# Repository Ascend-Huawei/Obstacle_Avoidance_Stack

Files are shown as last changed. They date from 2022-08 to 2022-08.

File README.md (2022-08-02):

# HiFly obstacle avoidance stack
This is a custom hardware sensor module to bring obstacle avoidance capabilities to small robotics. It is a fully independent module based on Arduino Nano IoT 33.

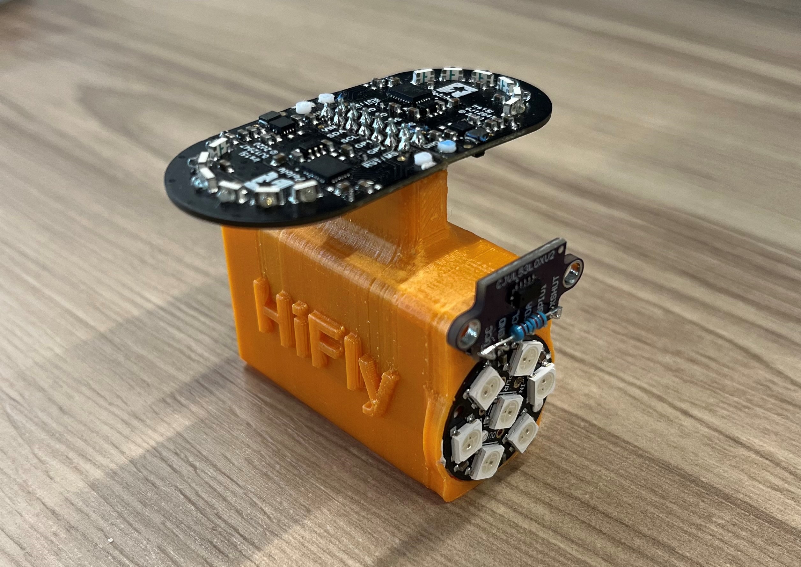
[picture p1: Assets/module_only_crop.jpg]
image info


## Features
General
 - Wifi 
 - Bluetooth
 - Independent Lipo battery based power system
 - 7 RBG LED ring for display or user interaction
 - Total weight only 35g

 Sensing
 - 360 degree lateral ToF sensing using 6 wide FoV channels
 - 1 narrow ToF sensor facing forward
 - 6 axis IMU

## Required knowledge to do the assembly
- 3D printing 
- Arduino/MCU programming
- Electronics - soldering, dupont connectors, etc

## Links
- [Assembly guide](ASSEMBLY.md)
- HiFly repo

# Parts list

### MCU
- [Arduino Nano iot 33](https://www.amazon.ca/Arduino-Nano-33-IoT/dp/B07VW9TSKD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)

### Sensors
- 2 x [OPT3101](https://www.robotshop.com/ca/en/3-channel-wide-fov-time-of-flight-distance-sensor-opt3101-no-headers.html)
- [ToF VL53L0X](https://www.amazon.ca/gp/product/B097SJ37DX/ref=ppx_yo_dt_b_search_asin_title?ie=UTF8&psc=1)

### Display
- [Adafruit NeoPixel Jewel](https://www.amazon.ca/gp/product/B00Q9R8QUO/ref=ppx_yo_dt_b_search_asin_title?ie=UTF8&psc=1) 

### Power
- [Battery, connector](https://www.amazon.ca/gp/product/B08NYDQ3HZ/ref=ppx_yo_dt_b_search_asin_title?ie=UTF8&psc=1)
- [Power converter](https://leeselectronic.com/en/product/15123-pololu-5v-step-up-voltage-regulator-u1v11f5.html)

### Circuit components (available in many kits)
- 30 AWG wires
- 2 NPN 8050 transistors
- 3 10k ohm resistors
- Dupoint wiring kit (be able to make 2x7, 1x6 connections)
- switch (available in many kits)

### Assembly
- 3D printing tools
- soldering tools
- tweezers, clippers, etc very useful

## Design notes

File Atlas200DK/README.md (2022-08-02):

# HiFly Obstacle Avoidance System
This is a setup guide to connect Tello Drone, Atlas200DK devkit board, Obstacle Avoidance Stack components together through WiFi communication.

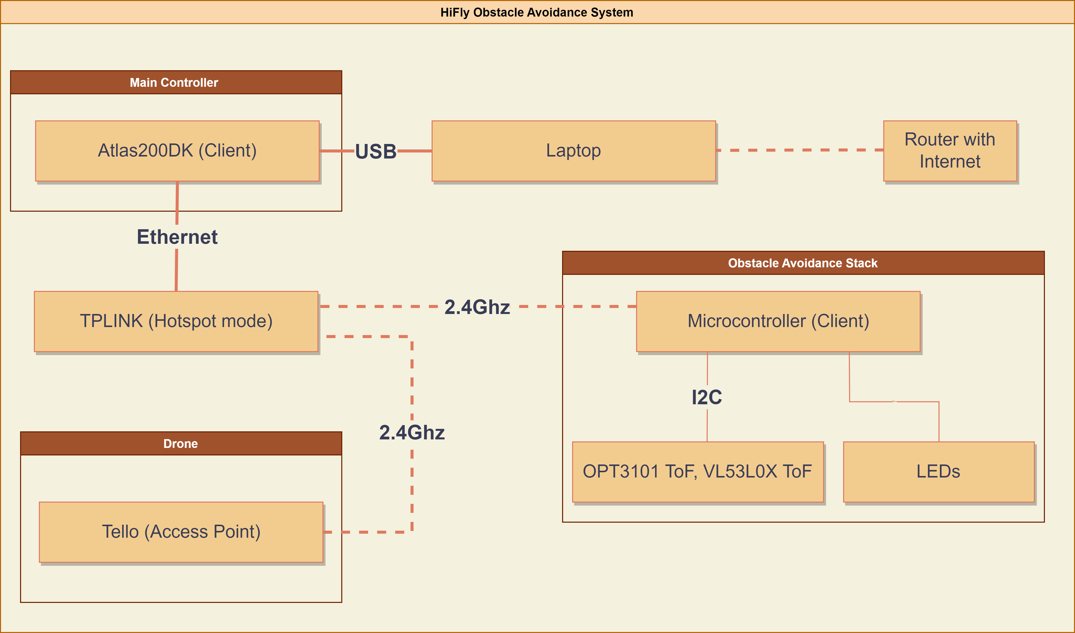
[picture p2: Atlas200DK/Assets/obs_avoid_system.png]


## Prerequisites
- Atlas200DK HiFly project setup finished 
- Obstacle Avoidance Stack setup finished

## Setup files and networking
The Arduino in the Obs Avoidance stack sends data to a specific IP and port defined in its code. This has to be the IP of the Atlas200DK and the port defined in the tello.py. The 200DK and Arduino are on the same subnet as the TPLINK router, so communication between them is straightforward.

The Tello is on a different network, so port forwarding must be defined to allow the Atlas200DK to receive data from the Tello.

### Steps
- Move 4 files to the Atlas200DK - 01-netcfg.yaml, ObsAvoid.py, simple_takeoff.py, tello.py
- Setup TPLINK router: Connect 2.4Ghz to Tello, setup port forwarding
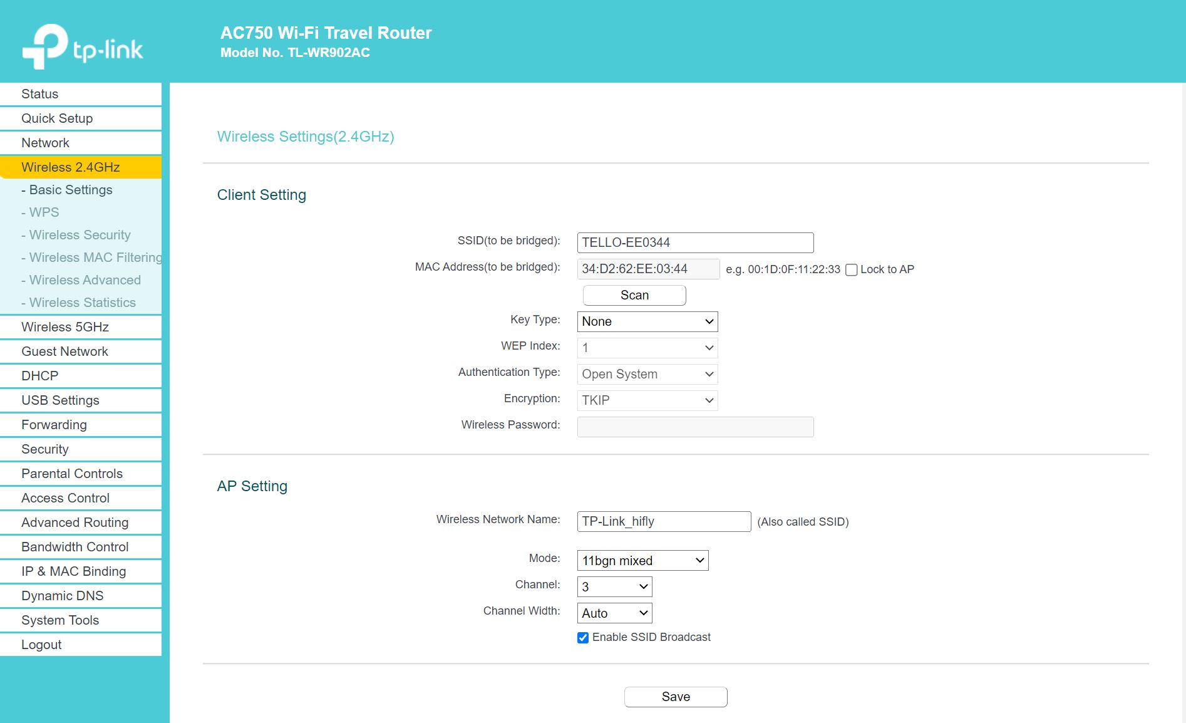
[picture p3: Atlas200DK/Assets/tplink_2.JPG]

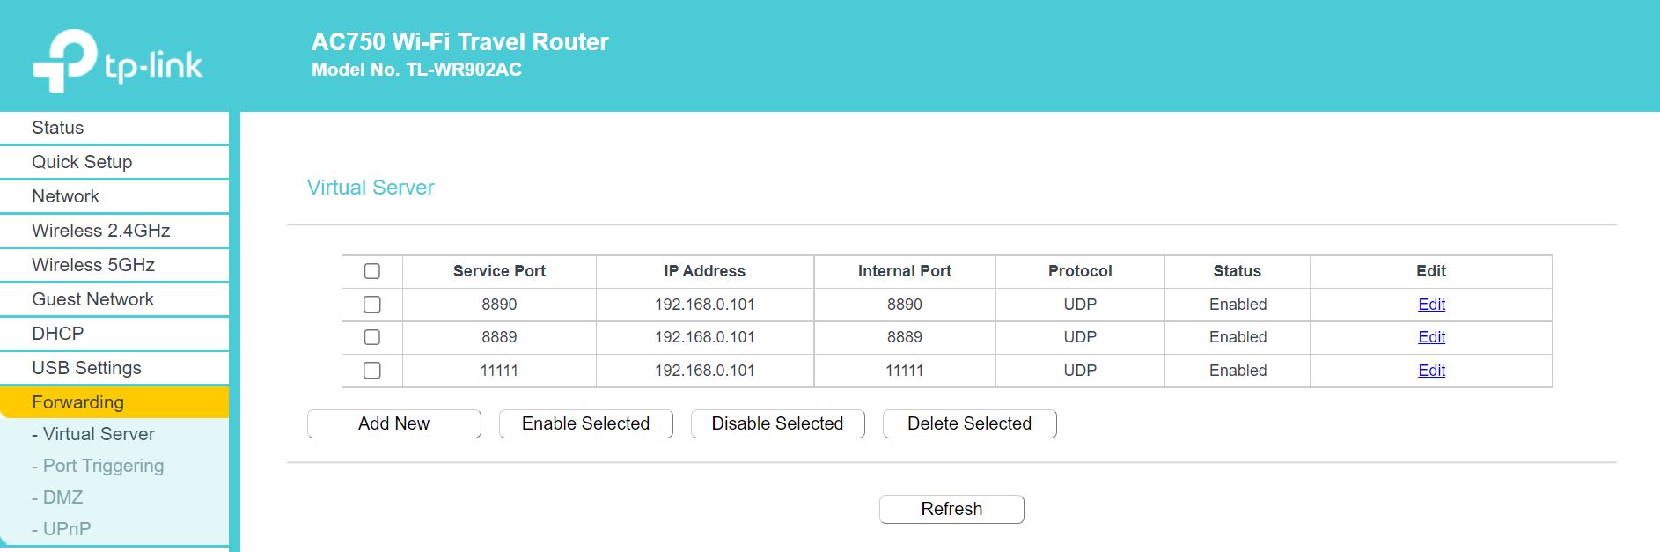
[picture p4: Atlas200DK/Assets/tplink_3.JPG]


- Change the netcfg.yaml under /etc/netplan/*.yaml to the new 01-netcfg.yaml

- From the Atlas200DK, try the following ping tests. If all works, networking setup is successful!: 
    - ping 192.168.0.1      # Router
    - ping 192.168.0.102    # Arduino
    - ping 192.168.1.0      # Tello

- Change the pip installed tello.py to the new tello.py. The installed one can be found by the python code: from djitellopy import Tello, print(tello.__file__)

## Running example
The intended core functionality of this project is access to Obstacle Avoidance sensor readings from the Atlas200DK through the modified tello.py class. A simple algorithm to process these sensor readings and return velocities which can be used to avoid the sensed obstacles is also provided, but only for basic demonstration purposes.

The simple_takeoff.py script uses the calculate_drone_velocity from ObsAvoid.py to implement the above mentioned basic algorithm. Set the LIVE_FLAG inside the script to either only print the sensor readings and computed velocities, or actually send them to the Tello drone.
- python3 simple_takeoff.py

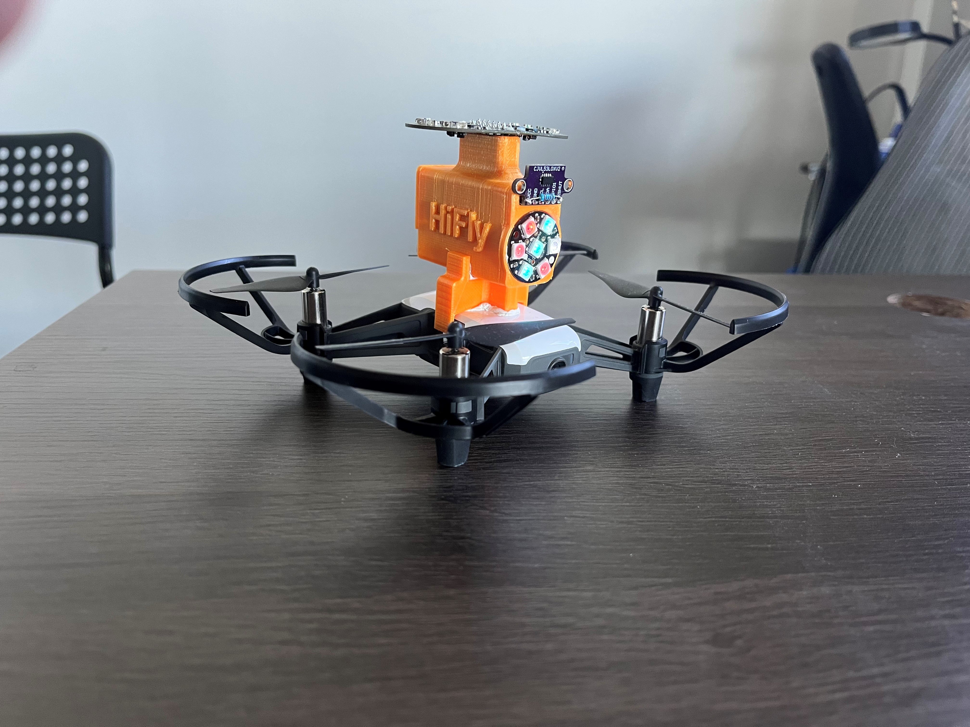
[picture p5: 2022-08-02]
Assets/module_drone.jpg

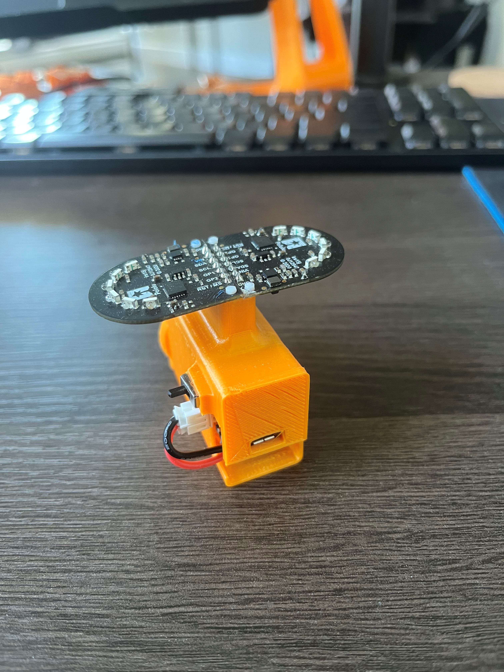
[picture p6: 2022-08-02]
Assets/hatch4.jpg

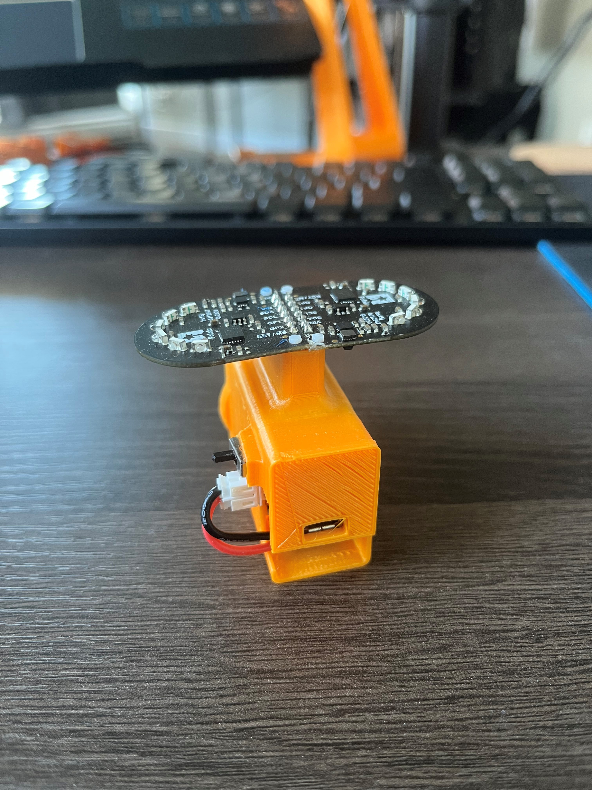
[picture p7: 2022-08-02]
Assets/hatch2.jpg

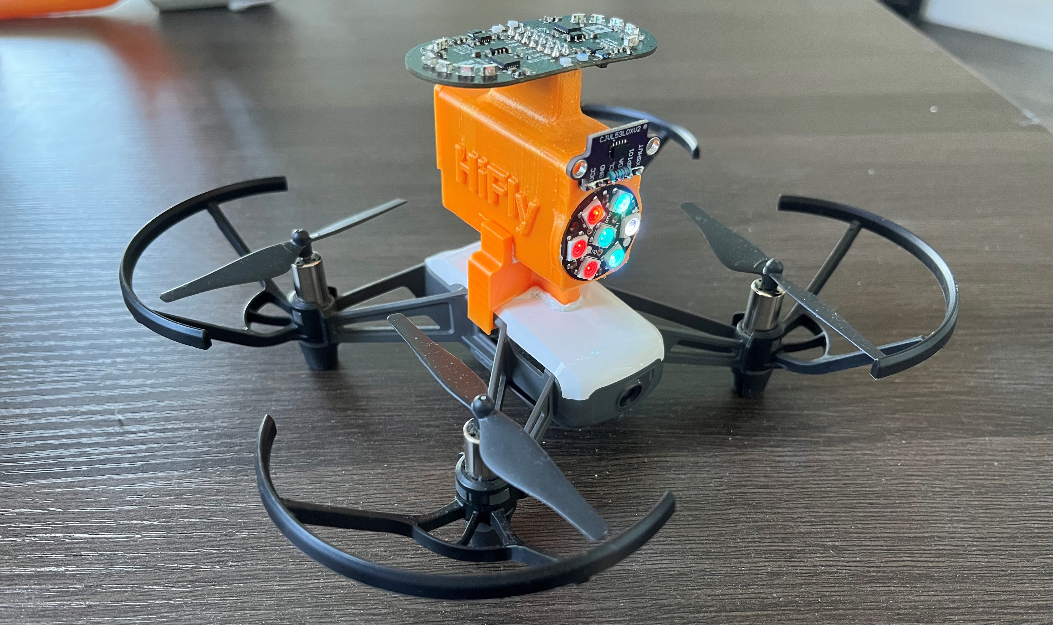
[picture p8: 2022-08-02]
Assets/module_drone2_crop.jpg

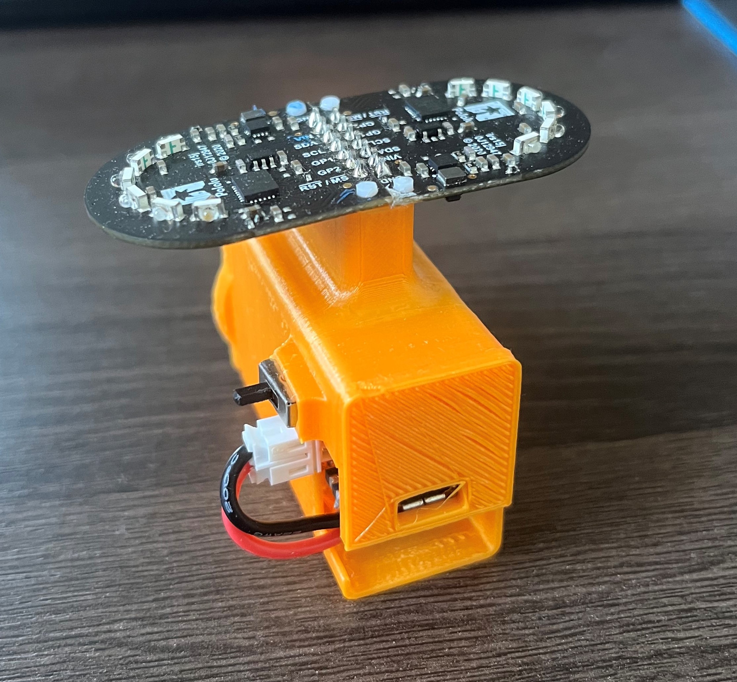
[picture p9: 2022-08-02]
Assets/hatch.jpg

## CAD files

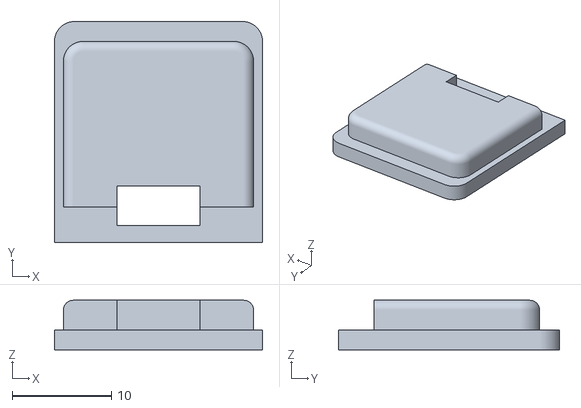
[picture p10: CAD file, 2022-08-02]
CAD/back_cover.stl
21.0 x 22.3 x 5.00

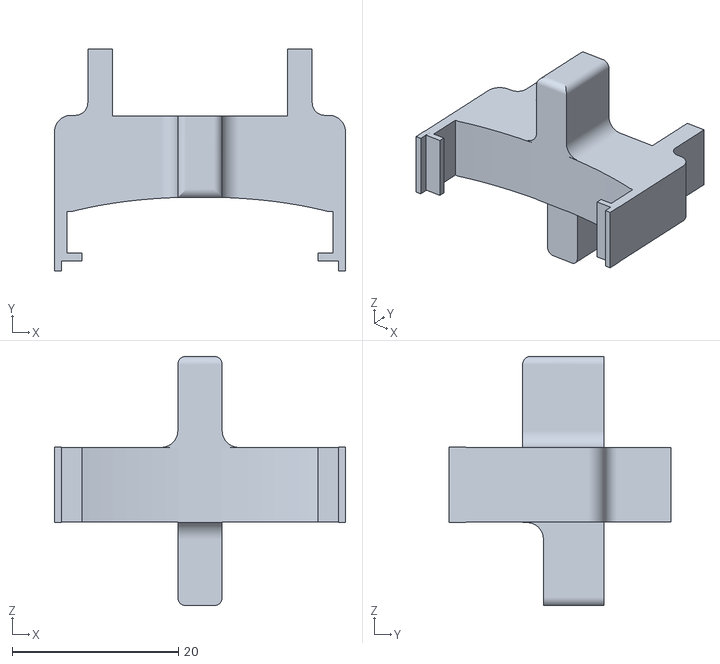
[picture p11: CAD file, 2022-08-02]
CAD/tello_clip.stl
35.0 x 26.8 x 30.0

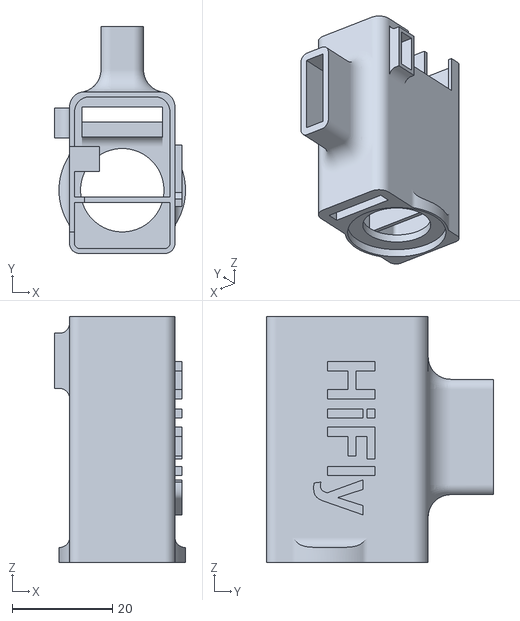
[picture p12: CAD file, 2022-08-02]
CAD/shell.stl
26.1 x 45.2 x 49.0

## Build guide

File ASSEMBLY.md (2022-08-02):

# Arduino packages to download
- WiFiNINA
- Adafruit NeoPixel
- DFRobot_VL53L0X
- OPT3101
# 3D printing the frame
- The frame is one large part, can be printed facing downwards (LED side on bed) and only using supports for the 'chimney' and LED ring.

- There is another small part to pop into the back, used to enclose the frame.

- When using with the DJI Tello drone, there is also a clip-mount component available.

# OPT3101 same I2C address workaround
The OPT3101 sensors share a hardcoded I2C address, which is an issue when we want to use two or more of them at the same time. The workaround used here is to use transistors to control which sensor the SDA line is connected to. The transistors can be toggled through the firmware to select which sensor to read from.

# Preparing the electronics
- Solder the two resistors and NPN transistors together according to the schematic. You can also add a heatshrink wrap the whole resistor branch.

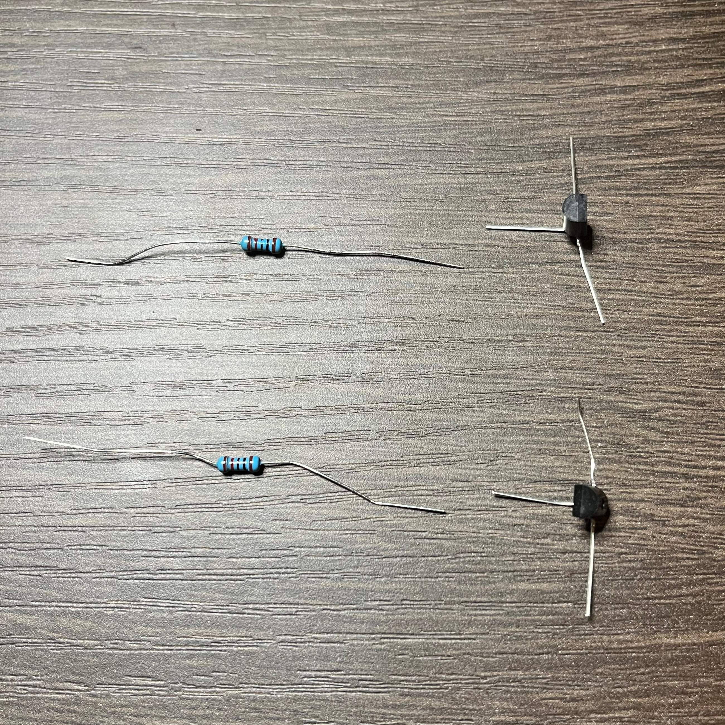
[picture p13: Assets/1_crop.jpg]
- - 
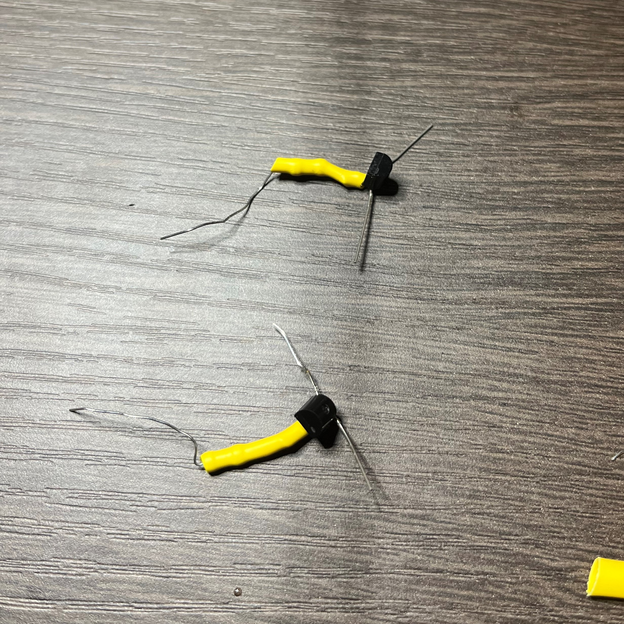
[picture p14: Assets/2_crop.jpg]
- - 

- Solder this combined component to the arduino according to the schematic. Try to have the component as flat as possible to conserver space.

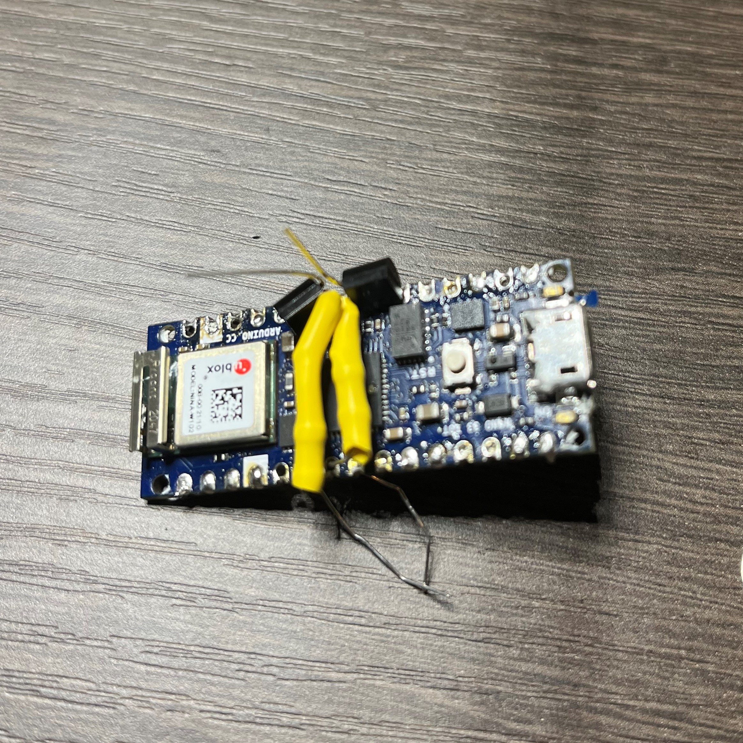
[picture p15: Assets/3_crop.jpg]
- - 

- Solder the 4 Vdd wires and 5 GND wires to the arduino, apply shrinkwrap.
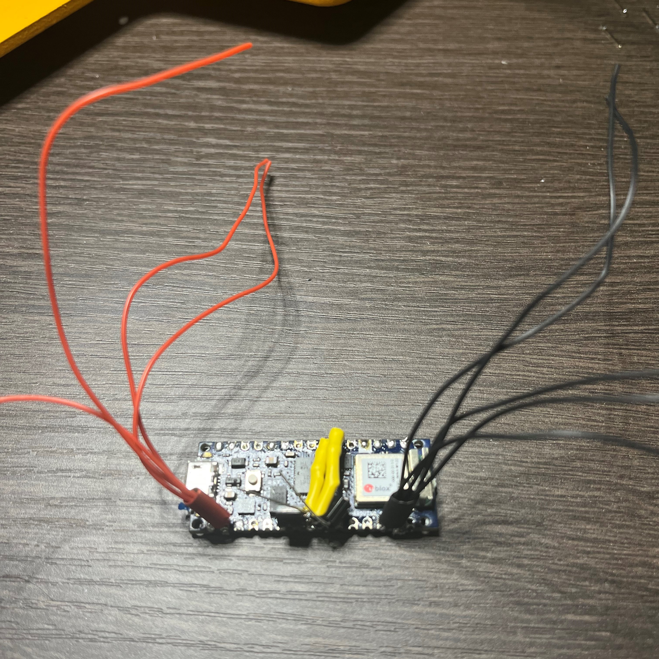
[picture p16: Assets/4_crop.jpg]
- - 

- Solder the Vin and 3 I2C scl wires to the arduino.
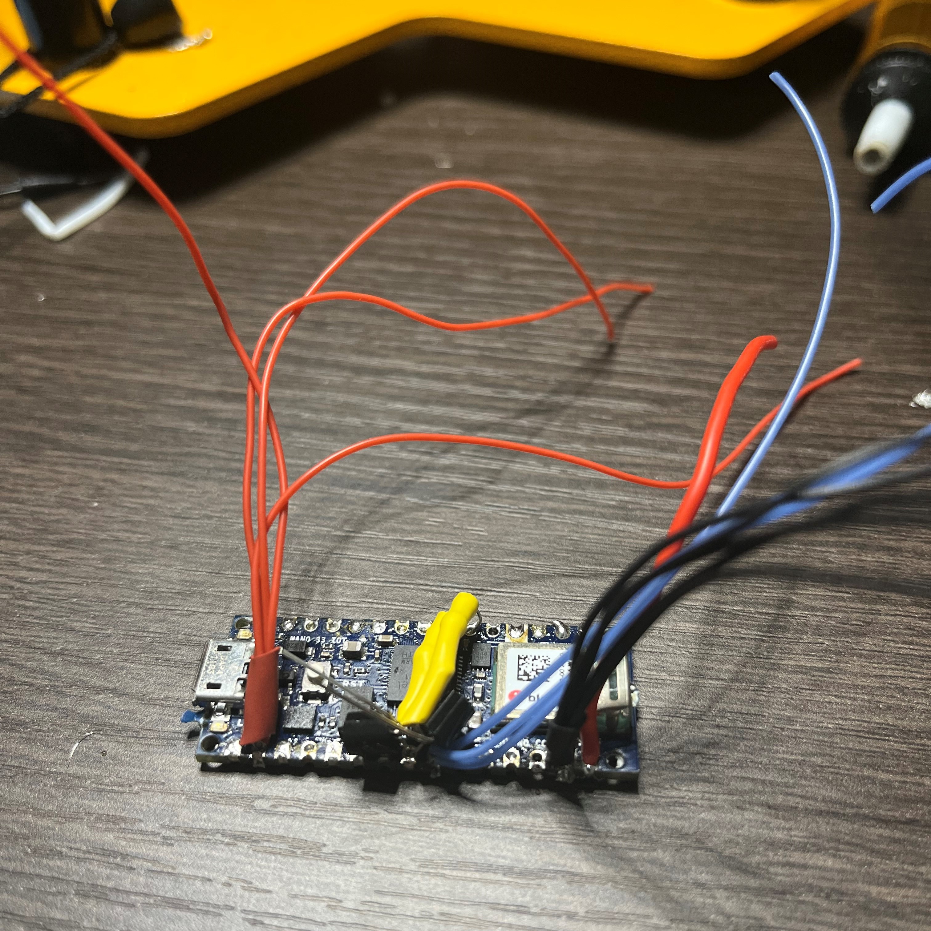
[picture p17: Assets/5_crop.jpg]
- - 

- Solder the 3 I2C sda wires and the 1 LED signal wire to the arduino.
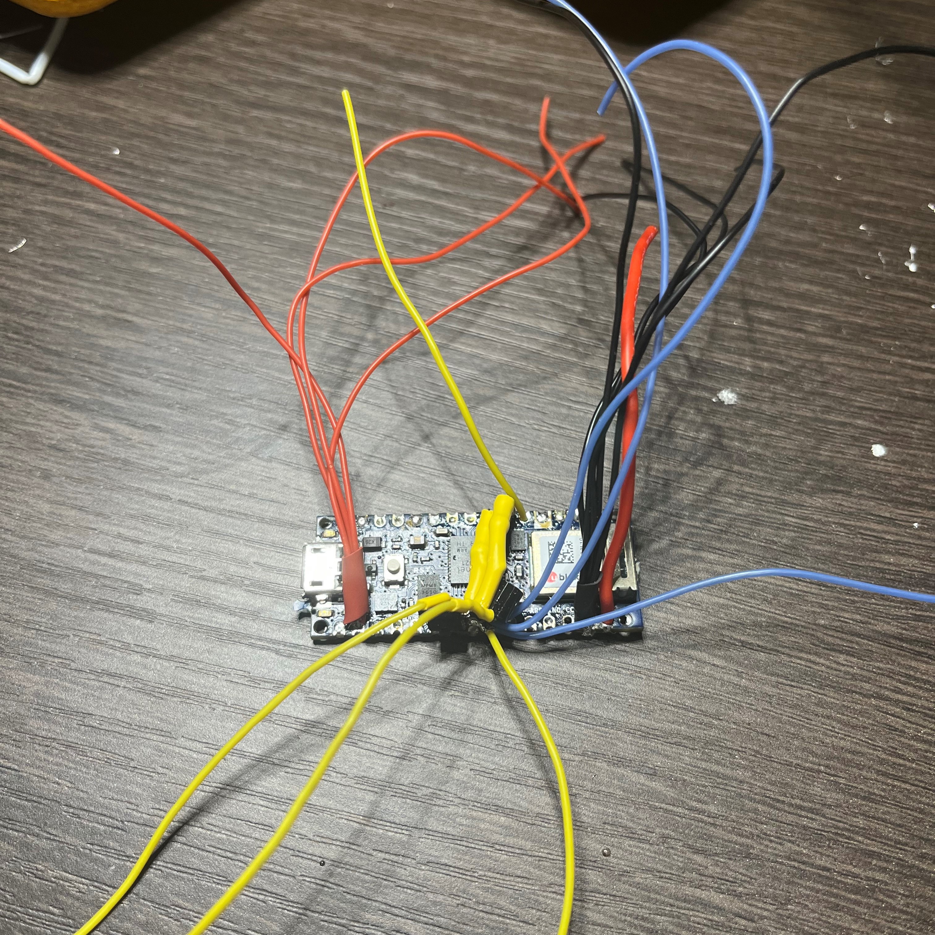
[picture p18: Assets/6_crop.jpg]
- - 

- With all the arduino wires soldered, the next step is to prepare the wires for each component by tieing them together.
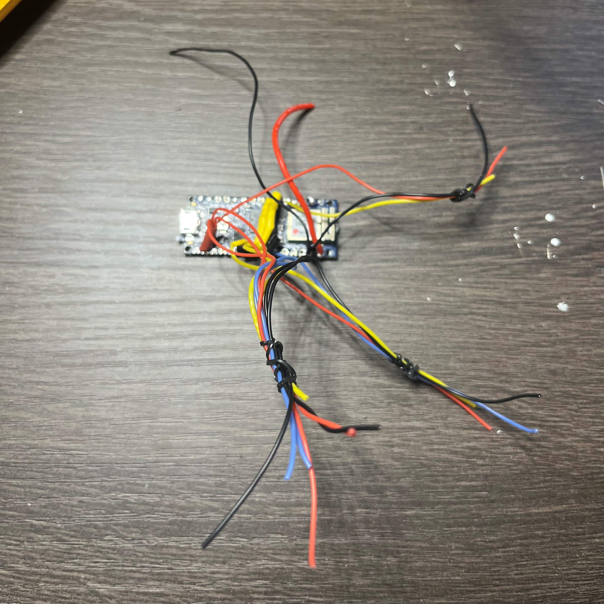
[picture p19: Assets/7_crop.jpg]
- - 

- Once the 4 wire batches are wrapped, the arduino can be inserted into the frame. A tweezer is useful for this step as each wire batch has to go through its corresponding slot.
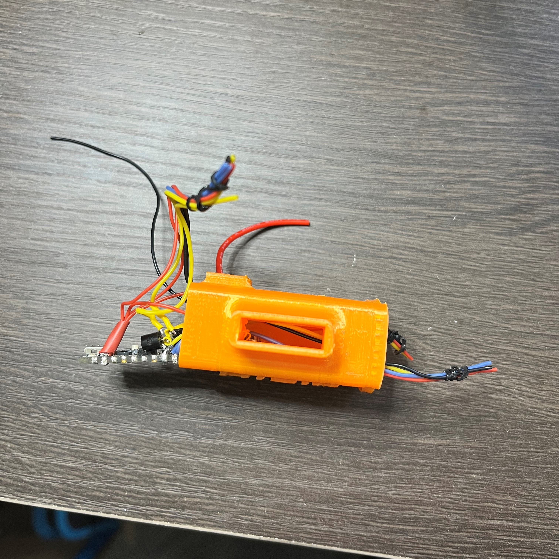
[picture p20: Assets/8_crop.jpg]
- - 
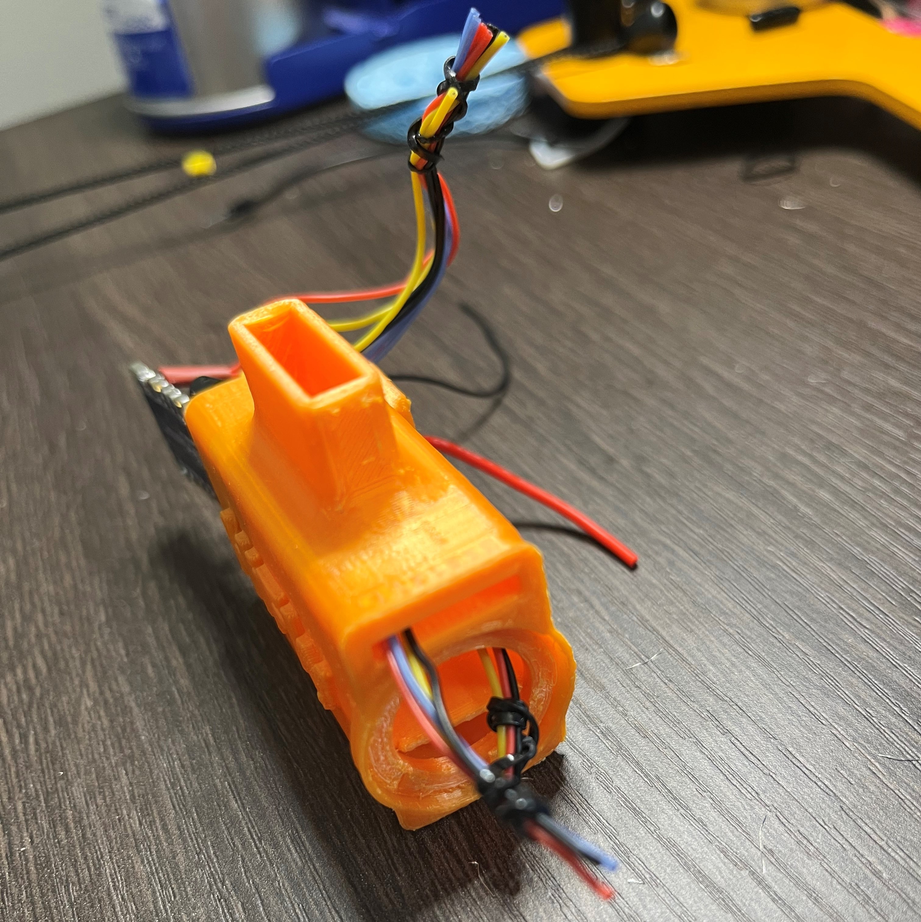
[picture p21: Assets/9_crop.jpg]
- - 
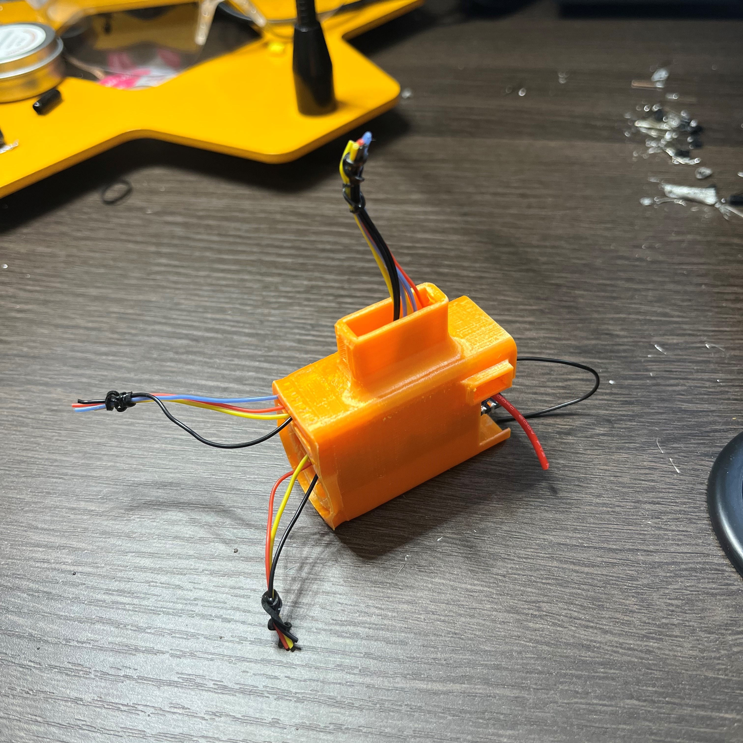
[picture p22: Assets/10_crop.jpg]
- - 

- Once the arduino is in the frame and the wires are all through the right slots, the power system components can be prepared and soldered to the GND and Vin wires of the arduino.
- A dummy program can be used to test wether the power system is working to power the arduino. Beware though that with the loads connected there can still be issues.
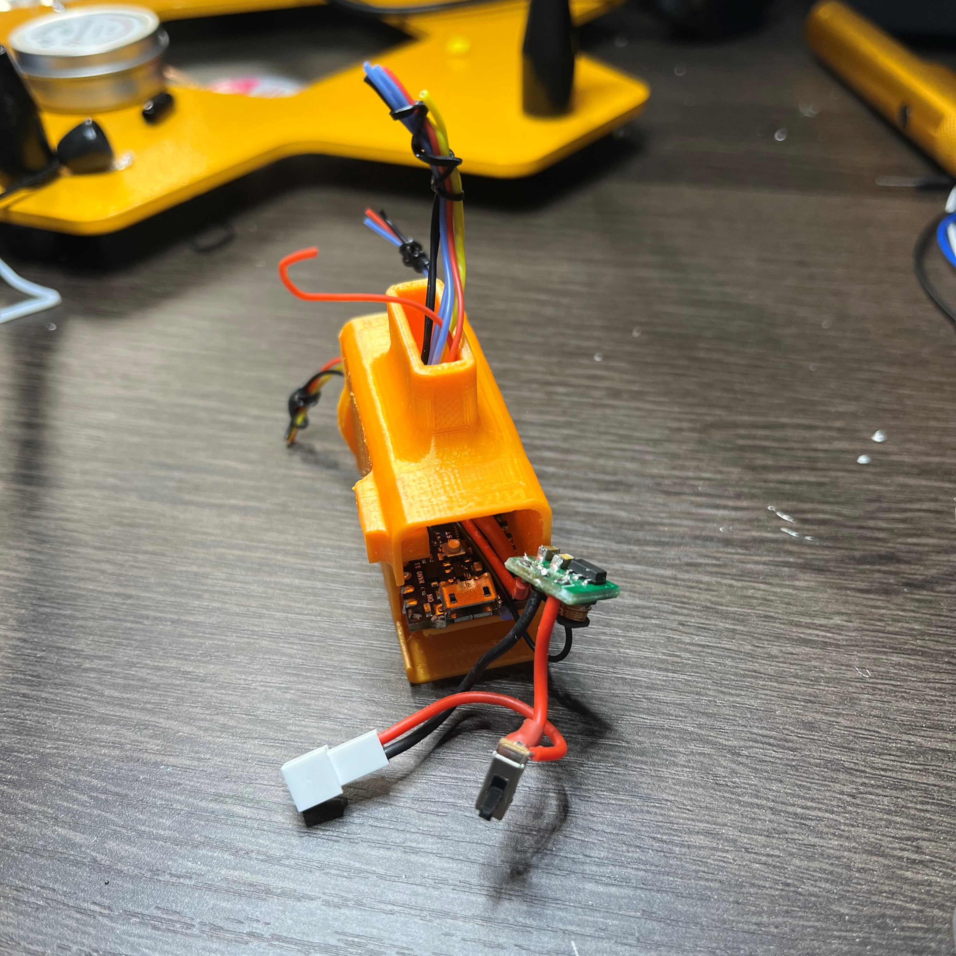
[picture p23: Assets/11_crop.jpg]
- - 

- If the power is working, the next step is to attach the components. First, the LED ring can be directly soldered to its wires, then use some adhesive to mount it into its slot.

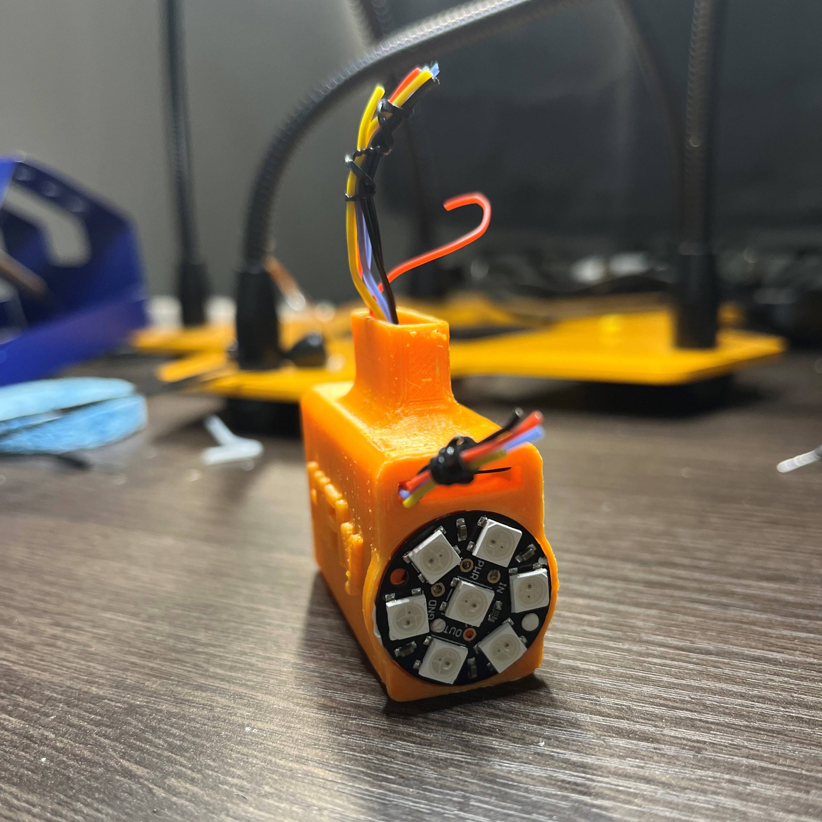
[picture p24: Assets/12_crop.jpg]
- - 

- Next, a 1x6 dupont connecting should be made for the front facing ToF sensor.

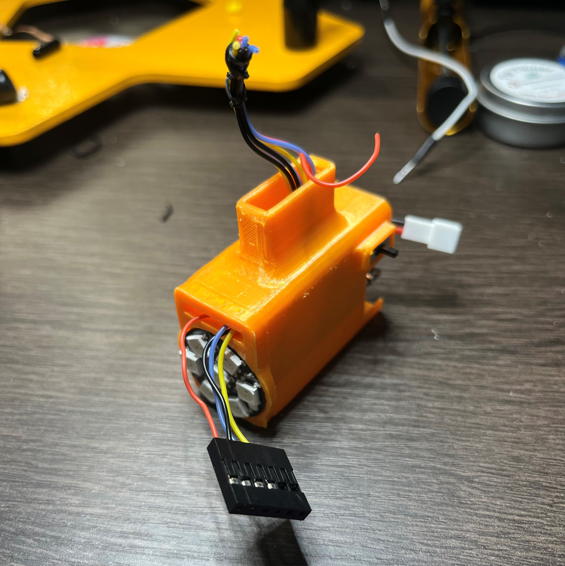
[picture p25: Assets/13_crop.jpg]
- - 

- Finally, a 2x7 dupont connection should be made for the 2 OPT3101 sensors on top. Make sure to attach the wires to the right positions as the two sensor pins are not aligned - eg the Vdd pins are not next to eachother.

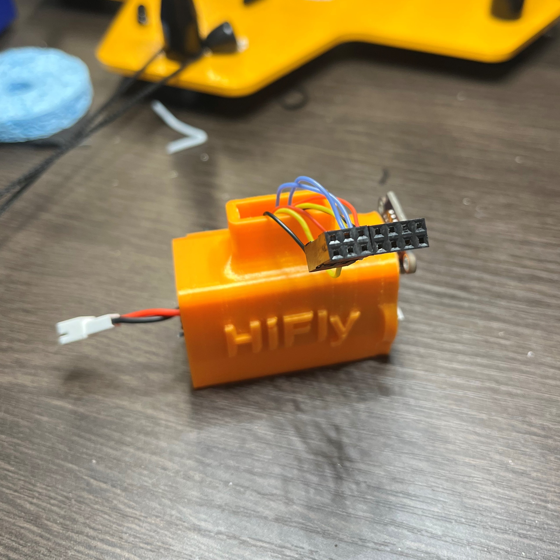
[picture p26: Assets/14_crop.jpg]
- - 

- Once the dupont connectors are pushed into the frame, the sensors can be simply plugged in. For the ToF sensor, a resistor should be soldered accross from the Vin to the shutdown pin before plugging it in.

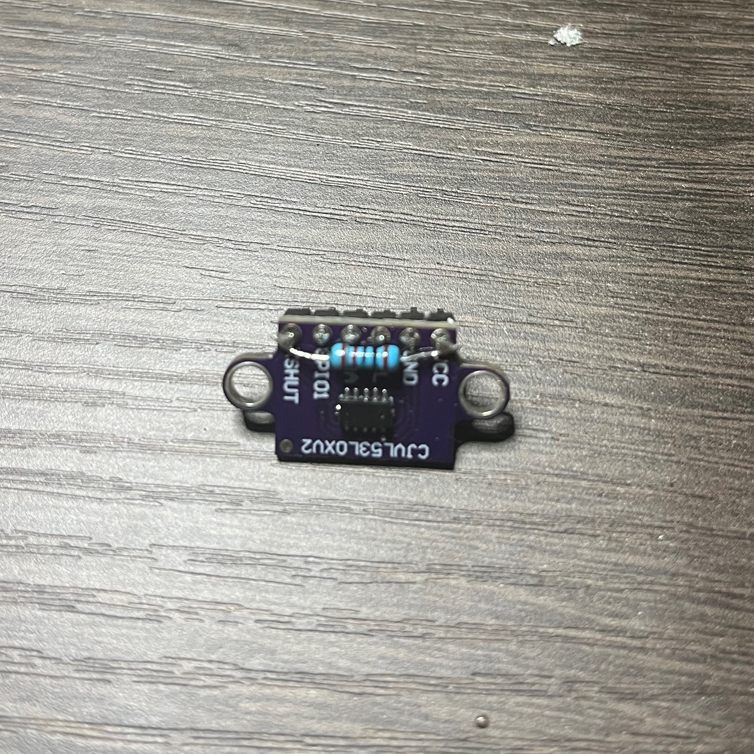
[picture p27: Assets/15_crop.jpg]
- - 

- The 2 OPT3101 sensor can be simply plugged in from the top. If there is not enough friction to keep the dupont connector in place, you can use the tweezers to support it from the bottom while plugging the sensors in.
image info

- Finally, the whole system can be tested with the battery plugged in. If everyhting is working, the battery plug can be superglued to its mounting spot and the back cover part can be snapped onto the back of the frame. The assembly is done!
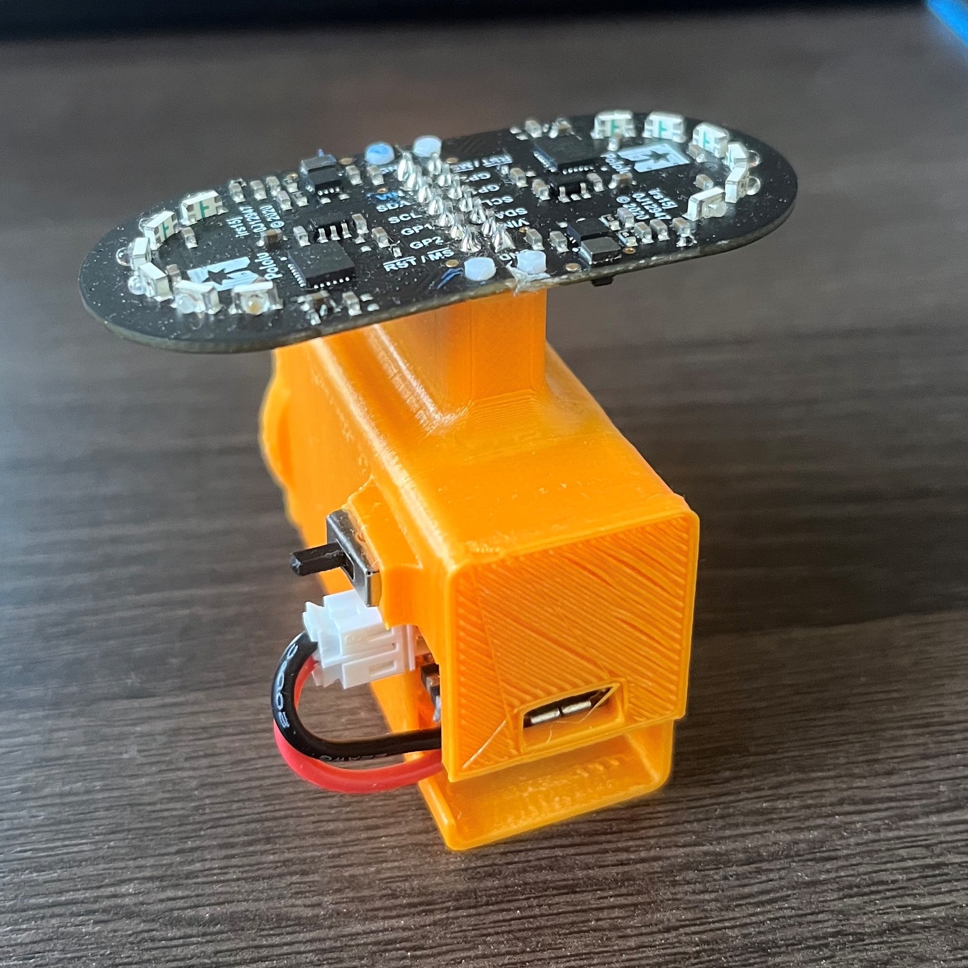
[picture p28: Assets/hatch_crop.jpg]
--

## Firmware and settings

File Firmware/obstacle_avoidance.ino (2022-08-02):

 /*
 * --- HiFly obstacle avoidance sensor stack for Tello ---
 * Description:
 * This program utlizies 2 OPT3101 sensors and one VL53L0X ToF sensor.
 * All the sensor readings are sent through wifi to a static IP and port.
 * An LED matrix (8 LEDs) is used to provide direct feedback on the sensor readings.
 * The LED matrix is also used to implement user-feedback functionality such as a green blink.
 * 
 * Author: Benedek Hegedus, Huawei Canada
 */

// ---- DEBUG START ----
#define LED_PWR 13
int led_1_blink_time = 200;
long led_1_last_blink;
// ---- DEBUG END ----


// ------ WIFI START ------
#include <SPI.h>
#include <WiFiNINA.h>
#include <WiFiUdp.h>



// ------###### NETWORK CONFIG START ######------

#define SECRET_SSID "TP-Link_hifly"
#define SECRET_PASS ""
 
IPAddress local_ip(192, 168, 0, 152); // for static ip   

#define ATLASDK_IP "192.168.0.101"
const int16_t ATLASDK_PORT = 9121;

// ------###### NETWORK CONFIG END ######------



int status = WL_IDLE_STATUS;
char ssid[] = SECRET_SSID;        // your network SSID (name)
char pass[] = SECRET_PASS;    // your network password (use for WPA, or use as key for WEP)
int keyIndex = 0;            // your network key index number (needed only for WEP)

unsigned int localPort = 2390;      // local port to listen on

char packetBuffer[8]; //buffer to hold incoming packet
char  ReplyBuffer[] = "acknowledged";       // a string to send back

bool send_flag = false;

WiFiUDP Udp;
// ------ WIFI END ------



// ------ VL53L0X ToF SENSOR START ------
#include "Arduino.h"
#include "DFRobot_VL53L0X.h"
DFRobot_VL53L0X tofSensor;
// ------ VL53L0X ToF SENSOR END ------



// ------ OPT3101 SENSOR START ------
#include <OPT3101.h>
#include <Wire.h>

const uint8_t TRANSISTOR_PIN_1 = 3;
const uint8_t TRANSISTOR_PIN_2 = 4;

const int16_t MAX_DISTANCE = 1000;
const int16_t MIN_DISTANCE = 1;

OPT3101 sensor1;
OPT3101 sensor2;
uint16_t amplitudes[6];
int16_t distances[7];
// ------ OPT3101 SENSOR END ------



// ------ 8 LED RGB START ------

#include <Adafruit_NeoPixel.h>
#ifdef __AVR__
 #include <avr/power.h> // Required for 16 MHz Adafruit Trinket
#endif

// Which pin on the Arduino is connected to the NeoPixels?
#define PIN        2 // On Trinket or Gemma, suggest changing this to 1

// How many NeoPixels are attached to the Arduino?
#define NUMPIXELS 8 // Popular NeoPixel ring size

#define DELAYVAL 500 // Time (in milliseconds) to pause between pixels

// When setting up the NeoPixel library, we tell it how many pixels,
// and which pin to use to send signals. Note that for older NeoPixel
// strips you might need to change the third parameter -- see the
// strandtest example for more information on possible values.
Adafruit_NeoPixel pixels(NUMPIXELS, PIN, NEO_GRB + NEO_KHZ800);

uint8_t RGB_values[3];

// ------ 8 LED RGB END ------

    


void setup()
{ 
 // DEBUG
  pinMode(LED_PWR, OUTPUT);

  // Init pins to switch between OPT sensors
  pinMode(TRANSISTOR_PIN_1, OUTPUT);
  pinMode(TRANSISTOR_PIN_2, OUTPUT);

  Wire.begin();
  
  Serial.println("Init Sensor 1 start");

  initLEDs(64); // init LEDs and set brightness to 64 (out of 255)

  setLEDs(1);

  initSensor1();

  initSensor2();

  setLEDs(2);

  init_tof_sensor();

  setLEDs(3);

  initWIFI();

  digitalWrite(LED_PWR, HIGH);

}

void loop()
{
  readOPTs();  
  readTofSensor();
  setLEDs();
  sendSensorData();
  handleRequest();


  // Blink built in LED to easly debug if Arduino crashes
  if((millis() - led_1_last_blink) >= led_1_blink_time){
    if(digitalRead(13) == HIGH){
      digitalWrite(13, LOW);
    }else{
      digitalWrite(13, HIGH);
    }
    led_1_last_blink = millis();
  }


  // Print sensor readings through serial - can be commented out 
  for (uint8_t i = 0; i < 7; i++)
  {
    Serial.print(distances[i]);
    Serial.print(", ");
  }
  
  Serial.println();
}



// ------ OPT3101 SENSOR FUNCTIONS START ------
void readOPTs(){
  startSensor1();
  startSensor2();
  finSensor1(0);
  startSensor1();
  finSensor2(0);
  startSensor2();
  finSensor1(1);
  startSensor1();
  finSensor2(1);
  startSensor2();
  finSensor1(2);
  finSensor2(2);
}

void startSensor1(){
  setSensor1();
  sensor1.startSample();
  return;
}

void startSensor2(){
  setSensor2();
  sensor2.startSample();
  return;
}

void finSensor1(uint8_t channel){
  setSensor1();
  int timeout_count = 0;
  while(!sensor1.isSampleDone() && timeout_count < 100000){
    timeout_count++;
  }
  if(timeout_count >= 100000){
    Serial.println("TIMEOUT!!!");
  }
  
  sensor1.readOutputRegs();
  distances[channel] = sensor1.distanceMillimeters;
  sensor1.nextChannel();
  return;
}

void finSensor2(uint8_t channel){
  setSensor2();
  int timeout_count = 0;
  while(!sensor2.isSampleDone() && timeout_count < 100000){
    timeout_count++;
  }
  if(timeout_count >= 100000){
    Serial.println("TIMEOUT!!!");
  }
  
  sensor2.readOutputRegs();
  distances[channel+3] =  sensor2.distanceMillimeters;
  sensor2.nextChannel();
  return;
}


void initSensor1(){
  setSensor1();

  sensor1.init();
  if (sensor1.getLastError())
  {
    //Serial.print(F("Failed to initialize OPT3101 1: error "));
    //Serial.println(sensor1.getLastError());
    while (1) {}
  }

  sensor1.setFrameTiming(128);
  sensor1.setChannel(0);
  sensor1.setBrightness(OPT3101Brightness::High);
  return;
}


void initSensor2(){
  setSensor2();

  sensor2.init();
  if (sensor2.getLastError())
  {
    //Serial.print(F("Failed to initialize OPT3101 2: error "));
    //Serial.println(sensor2.getLastError());
    while (1) {}
  }

  sensor2.setFrameTiming(128);
  sensor2.setChannel(0);
  sensor2.setBrightness(OPT3101Brightness::High);
  return;
}



void setSensor1(){
  delayMicroseconds(10);
  digitalWrite(TRANSISTOR_PIN_2, LOW);
  digitalWrite(TRANSISTOR_PIN_1, HIGH);
  delayMicroseconds(10);
  return;
}

void setSensor2(){
  delayMicroseconds(10);
  digitalWrite(TRANSISTOR_PIN_1, LOW);
  digitalWrite(TRANSISTOR_PIN_2, HIGH);
  delayMicroseconds(10);
  //setSensor1();
  return;
}
// ------ OPT3101 SENSOR FUNCTIONS END ------



// ------ RGB LED FUNCTIONS START ------

void setLEDs (){ 
  distanceToRGB(distances[0]);
  pixels.setPixelColor(1, pixels.Color(RGB_values[0], RGB_values[1], RGB_values[1]));

  distanceToRGB(distances[1]);
  pixels.setPixelColor(2, pixels.Color(RGB_values[0], RGB_values[1], RGB_values[1]));

  distanceToRGB(distances[2]);
  pixels.setPixelColor(3, pixels.Color(RGB_values[0], RGB_values[1], RGB_values[1]));

  distanceToRGB(distances[3]);
  pixels.setPixelColor(4, pixels.Color(RGB_values[0], RGB_values[1], RGB_values[1]));

  distanceToRGB(distances[4]);
  pixels.setPixelColor(5, pixels.Color(RGB_values[0], RGB_values[1], RGB_values[1]));

  distanceToRGB(distances[5]);
  pixels.setPixelColor(6, pixels.Color(RGB_values[0], RGB_values[1], RGB_values[1]));  
  

  distanceToRGB(distances[6]);
  pixels.setPixelColor(0, pixels.Color(RGB_values[0], RGB_values[1], RGB_values[1]));
  
  pixels.show();   // Send the updated pixel colors to the hardware.
  return;
}

// Uses RGB_values global array
void distanceToRGB(int16_t distance){
  int16_t bounded_distance = distance;
  
  if(distance >= MAX_DISTANCE){
    bounded_distance = MAX_DISTANCE;
  }
  if(distance < MIN_DISTANCE){
    bounded_distance = MIN_DISTANCE;
  }

  float distance_percent = (float)(bounded_distance - MIN_DISTANCE) / (float)(MAX_DISTANCE - MIN_DISTANCE);
 
  RGB_values[0] = (int8_t)((1.0 - distance_percent) * 10.0); // scale RED inverse with distance
  RGB_values[1] = (int8_t)(distance_percent * 10.0); // scale GREEN directly with distance
  RGB_values[2] = 0;

  return;
}

void initLEDs(uint8_t brightness){
  // These lines are specifically to support the Adafruit Trinket 5V 16 MHz.
  // Any other board, you can remove this part (but no harm leaving it):
  
  #if defined(__AVR_ATtiny85__) && (F_CPU == 16000000)
  clock_prescale_set(clock_div_1);
  #endif
  // END of Trinket-specific code.

  pixels.begin(); // INITIALIZE NeoPixel strip object (REQUIRED)
  pixels.setBrightness(brightness);
  pixels.clear(); // Set all pixel colors to 'off'
  return;
}


void setLEDs(uint8_t color){
  // set LED green
  pixels.clear(); // Set all pixel colors to 'off'
  for(int i=0; i<7; i++) { 

    // pixels.Color() takes RGB values, from 0,0,0 up to 255,255,255
    if (color == 0){
    pixels.setPixelColor(i, pixels.Color(0, 0, 0));
    }
    if (color == 1){
    pixels.setPixelColor(i, pixels.Color(50, 0, 0));
    }
    if (color == 2) {
    pixels.setPixelColor(i, pixels.Color(0, 50, 0));
    }
    if (color == 3) {
    pixels.setPixelColor(i, pixels.Color(0, 0, 50));
    }
    pixels.show();   // Send the updated pixel colors to the hardware.

  }
  return;
}
// ------ RGB LED FUNCTIONS END ------



// ------ ToF SENSOR FUNCTIONS START ------
void init_tof_sensor(){
  // default address is 0x50
  tofSensor.begin(0x50);
  //Set to Back-to-back mode and high precision mode
  tofSensor.setMode(tofSensor.eContinuous,tofSensor.eHigh);
  //Laser rangefinder begins to work
  tofSensor.start();
  return;
}

void readTofSensor(){
  distances[6] = tofSensor.getDistance();
  return;
}
// ------ ToF SENSOR FUNCTIONS END ------



// ------ WIFI FUNCTIONS START ------
void initWIFI(){
  // check for the WiFi module:
  if (WiFi.status() == WL_NO_MODULE) {
    Serial.println("Communication with WiFi module failed!");
    // don't continue
    while (true);
  }

 
  // attempt to connect to WiFi network:
  WiFi.config(local_ip);  // use static ip
  while (status != WL_CONNECTED) {
    Serial.print("Attempting to connect to SSID: ");
    Serial.println(ssid);
    // Connect to WPA/WPA2 network. Change this line if using open or WEP network:
    status = WiFi.begin(ssid, pass);

    // wait 10 seconds for connection:
    delay(3000);
  }
  //Serial.println("Connected to WiFi");
  printWifiStatus();

  //Serial.println("\nStarting connection to server...");
  // if you get a connection, report back via serial:
  Udp.begin(localPort);

  return;
}

void printWifiStatus() {
  // print the SSID of the network you're attached to:
  Serial.print("SSID: ");
  Serial.println(WiFi.SSID());

  // print your board's IP address:
  IPAddress ip = WiFi.localIP();
  Serial.print("IP Address: ");
  Serial.println(ip);

  // print the received signal strength:
  long rssi = WiFi.RSSI();
  Serial.print("signal strength (RSSI):");
  Serial.print(rssi);
  Serial.println(" dBm");
  return;
}

void sendSensorData(){

   int16_t bounded_distances[7];

   for(int i=0; i < 7; i++){
    if (distances[i] <= MIN_DISTANCE){
      bounded_distances[i] = MIN_DISTANCE;
    }
    else if (distances[i] > MAX_DISTANCE){
      bounded_distances[i] = MAX_DISTANCE;
    }
    else {
      bounded_distances[i] = distances[i];
    }
   }
  
   String semicolon = String(";");
   String sensorData = (String(bounded_distances[3]) + semicolon
                        + String(bounded_distances[4]) + semicolon  
                        + String(bounded_distances[5]) + semicolon  
                        + String(bounded_distances[0]) + semicolon  
                        + String(bounded_distances[1]) + semicolon  
                        + String(bounded_distances[2]) + semicolon 
                        + String(bounded_distances[6]));
                        
   Udp.beginPacket(ATLASDK_IP, ATLASDK_PORT);
   Udp.write(sensorData.c_str());
   //Serial.println(sensorData);
   Udp.endPacket();
   return;
}


// Run a function based on value received 
void handleRequest(){
  // if there's data available, read a packet
  int packetSize = Udp.parsePacket();
  
  if (packetSize) {
    // read the packet into packetBufffer
    int len = Udp.read(packetBuffer, 7);
    if (len > 0) {
      packetBuffer[len] = 0;
    }
    
    Serial.println("Contents:");
    Serial.println(packetBuffer);

    if(packetBuffer[0] == '1'){
      userFeedback1();
    }
    if(packetBuffer[0] == '2'){
      userFeedback2();
    }
    
    // Not used by default, but can use for condition start
    // sending sensor data.
    if(packetBuffer[0] == '5'){
      startSending();
    }    
  }
  return;
}

void userFeedback1(){
  // Blink LED GREEN
  pixels.clear(); // Set all pixel colors to 'off'
  for(int i=0; i<7; i++) { 

    // pixels.Color() takes RGB values, from 0,0,0 up to 255,255,255
    pixels.setPixelColor(i, pixels.Color(0, 100, 0));
    pixels.show();   // Send the updated pixel colors to the hardware.

  }
  delay(200); // Delay so that user can notice blink
  return;
}

void userFeedback2(){
  // Blink LED BLUE
  pixels.clear(); // Set all pixel colors to 'off'
  for(int i=0; i<7; i++) { 

    // pixels.Color() takes RGB values, from 0,0,0 up to 255,255,255
    pixels.setPixelColor(i, pixels.Color(0, 0, 100));
    pixels.show();   // Send the updated pixel colors to the hardware.

  }
  delay(1000); // Delay so that user can notice blink
  return;
}

// By default, always sending sensor data,
// so this is not needed.
void startSending(){
  send_flag = true;
  return;
}


// ------ WIFI FUNCTIONS END ------
